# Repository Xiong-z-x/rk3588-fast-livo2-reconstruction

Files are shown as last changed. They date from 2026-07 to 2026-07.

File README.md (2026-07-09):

# RK3588 / ELF2 FAST-LIVO2 Reconstruction

<p align="center">
  <b>LiDAR-Visual-Inertial mapping stack for Livox Mid-360, Hikrobot MVS camera, STM32 hardware synchronization, ROS1 Noetic and WebGL visualization.</b>
</p>

<p align="center">
  
  
  
  
  
</p>

This repository collects the source code, launch scripts, calibration workflow, runtime configuration, mechanical design sources and visualization tools used in an embedded 3D reconstruction system. The project integrates Livox Mid-360 LiDAR, a Hikrobot industrial camera, STM32 hardware triggering and a ROS1 Docker runtime on an RK3588/ELF2-class board.

The repository is organized as a reproducible engineering package rather than a raw experiment dump. It contains the actual project source code, launch scripts, configuration templates, mechanical design sources, public submission materials and selected media assets. Large runtime data products such as rosbag files, PCD files and WebGL caches are intentionally excluded.

## Project Gallery

### Hardware

| Handheld acquisition kit | UAV platform |
| --- | --- |
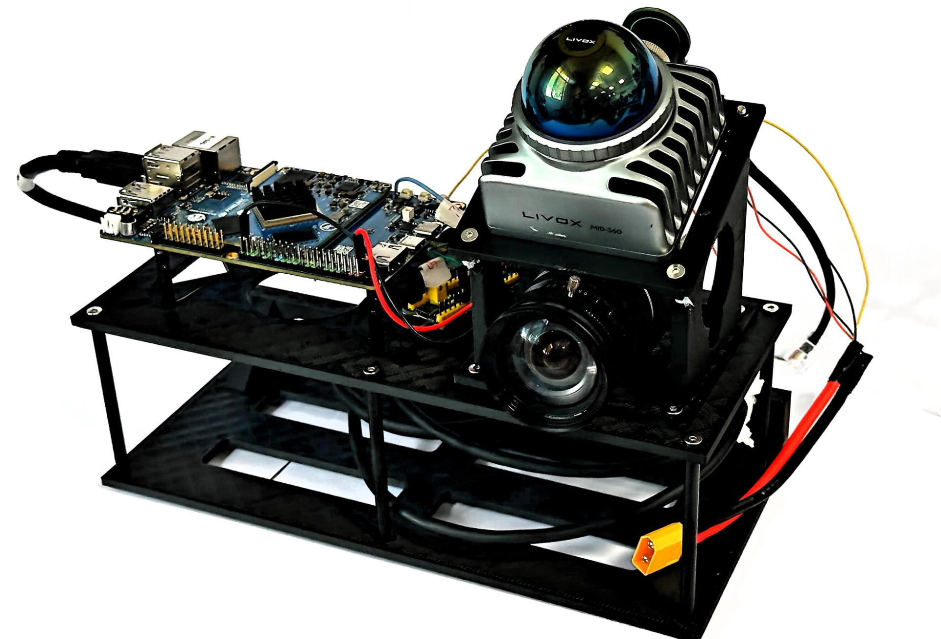
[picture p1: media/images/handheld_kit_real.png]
Handheld LiDAR-camera acquisition kit
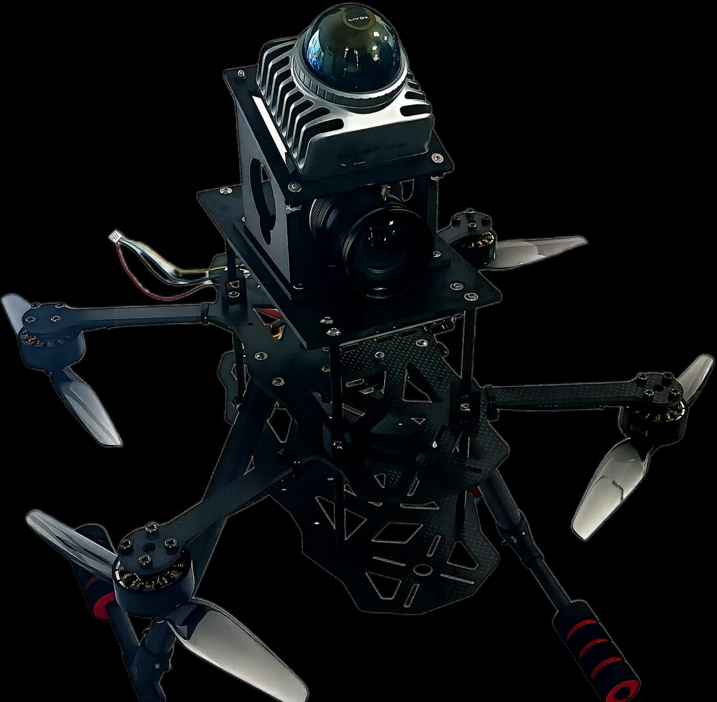
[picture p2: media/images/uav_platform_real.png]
UAV platform with mounted LiDAR-camera module
|  |  |

### Demonstration Videos

| Project demonstration | Progressive reconstruction | Point cloud result viewer |
| --- | --- | --- |
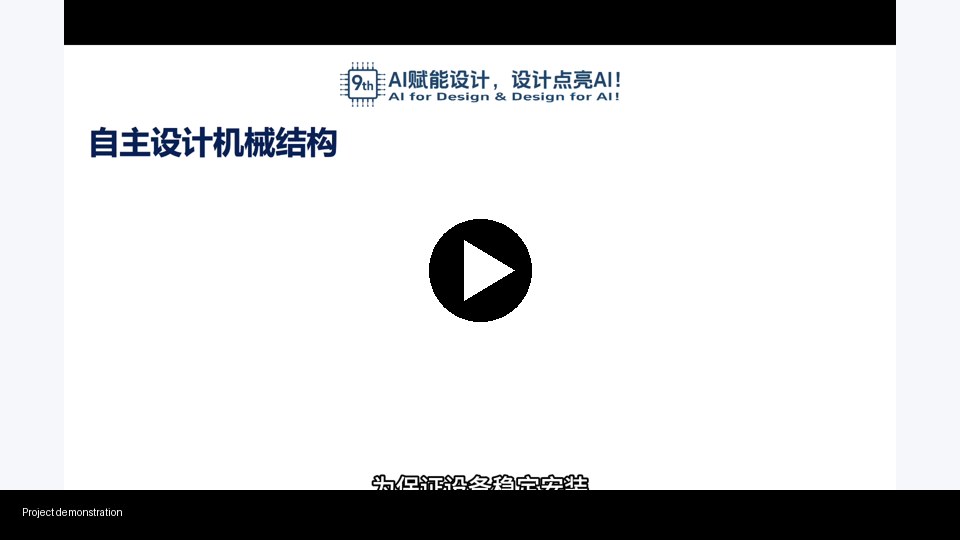
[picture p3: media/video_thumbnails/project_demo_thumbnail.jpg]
Project demonstration video
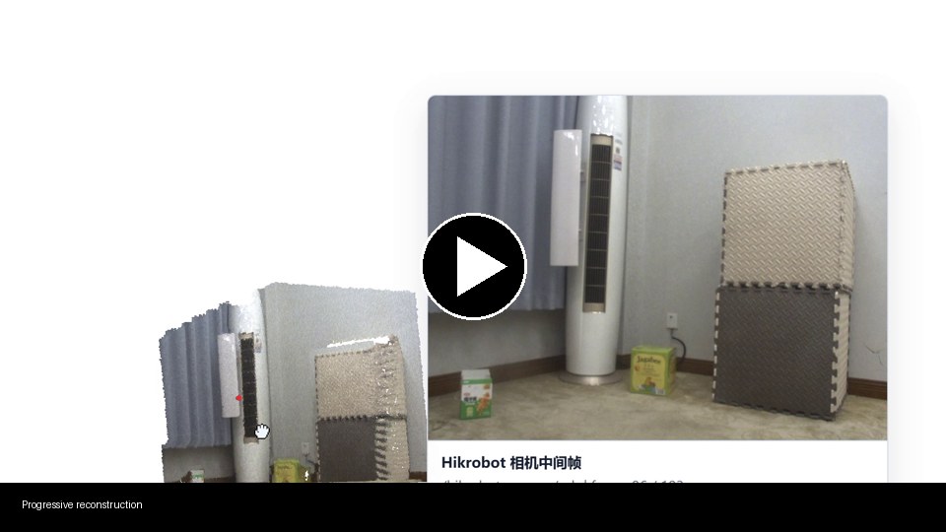
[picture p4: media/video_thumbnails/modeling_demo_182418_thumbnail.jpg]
Progressive reconstruction video
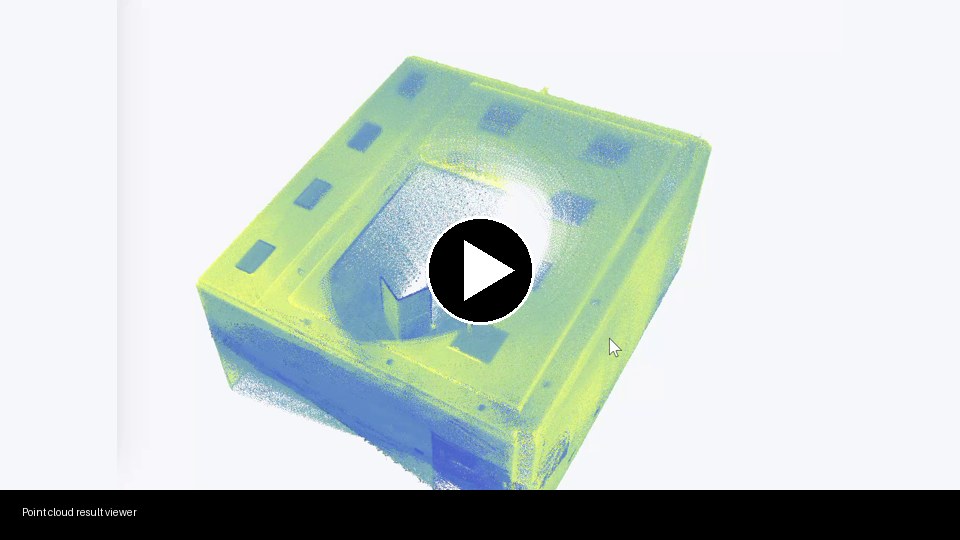
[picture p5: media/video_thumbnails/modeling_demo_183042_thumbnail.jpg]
Point cloud result viewer video
|  |  |  |

Click each thumbnail to open the original MP4 demonstration video.

## Highlights

- FAST-LIVO2-based LiDAR-visual-inertial reconstruction adapted for Mid-360 and Hikrobot image topics.
- LiDAR-only / ONLY_LIO workflow for scenes where the camera or hardware trigger is unavailable.
- Raw ROS bag acquisition scripts for `/livox/lidar`, `/livox/imu`, `/hikrobot_camera/rgb` and `/hikrobot_camera/camera_info`.
- Timestamp inspection utilities for camera duplicate stamps, frame gaps and synchronization diagnosis.
- Targetless visual-LiDAR extrinsic calibration workflow based on `direct_visual_lidar_calibration`.
- Point cloud export tools for colored FAST-LIVO2 output, registered intensity output, raw Livox accumulation and pose-accumulated height coloring.
- WebGL viewers for static multi-layer point clouds and progressive reconstruction playback.
- Read-only runtime dashboard with a real edge-status backend for ROS, Docker, CPU, memory and RKNPU status.

## Verification Status

This repository contains the project source files and engineering assets used in the RK3588/ELF2 reconstruction workflow. The committed source tree has passed the repository verification checks below:

- `python3 06_source_manifests/verify_submission_static.py`
- `git diff --check`
- Git LFS tracking for large MP4 media assets

The verification covers line endings, shell syntax, Python syntax, configuration templates, package layout, FAST-LIVO2/Livox dependency consistency and dashboard backend structure. Board deployment and reproduction steps are documented in [README_REPRODUCE.md](README_REPRODUCE.md).

## System Overview

```mermaid
flowchart LR
  L[Livox Mid-360] -->|/livox/lidar 10 Hz| R[ROS1 Docker]
  I[Mid-360 IMU] -->|/livox/imu 200 Hz| R
  C[Hikrobot camera] -->|/hikrobot_camera/rgb 10 Hz| R
  S[STM32 trigger] -->|hardware pulse| C
  R --> B[raw rosbag]
  B --> F[FAST-LIVO2 offline mapping]
  B --> O[ONLY_LIO mapping]
  F --> P[point cloud processing]
  O --> P
  P --> W[WebGL / RViz visualization]
```

## Repository Layout

```text
00_project_configuration/          Runtime topics, Docker, sensor and calibration templates
01_acquisition_and_recording/      Raw bag and LiDAR-only acquisition scripts
02_reconstruction_and_mapping/     FAST-LIVO2 offline, ONLY_LIO and point cloud processing
03_calibration/                    Camera intrinsics and targetless visual-LiDAR calibration scripts
04_visualization/                  WebGL, progressive reconstruction, RViz and ROS publishers
05_realtime_display/               Board status probe and web dashboard
06_source_manifests/               Source provenance records
07_full_source_code/               ELF2-adapted upstream source trees and project adaptation configs
08_edge_measurement_runtime/        Edge measurement and runtime integration programs
mechanical_design/                 SolidWorks mechanical design sources
media/                             Hardware images and demonstration videos
提交材料/                            Official submission package
submission_materials/              Final report and authorization material
docs/design/                       Architecture, synchronization, calibration and visualization notes
docs/evidence/                     Reproducibility records for build, rosbag, sync, runtime and reconstruction results
```

## Source Trees

The source directories are named with an `elf2` suffix to identify this repository's integration target. Upstream source provenance is preserved in `07_full_source_code/source_provenance/SOURCE_PROVENANCE.yaml`.

| Directory | Purpose |
| --- | --- |
| `07_full_source_code/FAST-LIVO2_elf2_mid360_hik/` | FAST-LIVO2 source tree used as the mapping core |
| `07_full_source_code/FAST-LIVO2_project_adaptation/` | Mid-360, Hikrobot and ONLY_LIO launch/config adaptation |
| `07_full_source_code/livox_ros_driver2_elf2_mid360/` | Livox ROS Driver2 source tree |
| `07_full_source_code/livox_ros_driver2_project_config/` | Mid-360 network config template for the board |
| `07_full_source_code/mvs_ros_driver_elf2_hikrobot/` | Hikrobot MVS ROS driver source tree |
| `07_full_source_code/mvs_ros_driver_project_config/` | Hikrobot trigger and calibration config template |
| `07_full_source_code/direct_visual_lidar_calibration_elf2/` | Targetless visual-LiDAR calibration source tree |

## Mechanical Design

The repository includes the SolidWorks source package imported from `D:\solidworks` under [`mechanical_design/solidworks_sources`](mechanical_design/solidworks_sources). The design files cover the E200 UAV platform, handheld acquisition fixture and embedded mounting structures for the Livox Mid-360, Hikrobot camera and RK3588/ELF2-class board.

The imported mechanical source package contains 697 valid design/reference files after excluding SolidWorks temporary lock files. CAD assets are tracked with Git LFS.

## Media and Submission Materials

- [云顶智量-展示视频](提交材料/云顶智量-展示视频.mp4)
- [云顶智量-报告](提交材料/云顶智量-报告.pdf)
- [云顶智量-代码](提交材料/云顶智量-代码.rar)
- [云顶智量-授权书](提交材料/云顶智量-授权书.pdf)
- [Final project report](submission_materials/yunding_zhiliang_final_report.pdf)
- [Authorization document](submission_materials/authorization.pdf)
- [Project demonstration video](media/videos/yunding_zhiliang_demo.mp4)
- [Reconstruction screen recording 2026-07-07 18:24](media/videos/modeling_reconstruction_demo_20260707_182418.mp4)
- [Reconstruction screen recording 2026-07-07 18:30](media/videos/modeling_reconstruction_demo_20260707_183042.mp4)

Large MP4 assets are tracked with Git LFS to keep the Git history usable while preserving the original submission videos.

## Runtime Environment

- Board class: RK3588 / ELF2
- ROS distribution: ROS1 Noetic
- Container model: Docker with host networking
- Primary LiDAR topic: `/livox/lidar`
- Primary IMU topic: `/livox/imu`
- Primary camera topic: `/hikrobot_camera/rgb`
- Camera info topic: `/hikrobot_camera/camera_info`
- Recommended offline playback rate: `0.5x` for stable reconstruction on limited embedded hardware

Public hardware configuration templates are named `.example.*`. Copy them to local files and fill in the actual serial numbers, MAC addresses and IP addresses before deployment. See [README_REPRODUCE.md](README_REPRODUCE.md) for the exact copy, validation, build and run sequence.

## Quick Start

Assemble the ROS1 workspace from the packaged source trees:

```bash
export RK3588_ROS_CONTAINER=${RK3588_ROS_CONTAINER:-rk3588_dev}
export RK3588_WS=${RK3588_WS:-/root/fast_lio2_ws}

./00_project_configuration/create_catkin_workspace_from_submission.sh \
  --workspace "$RK3588_WS" \
  --copy
```

Use `--with-calibration` only when the review machine also has the dependencies required by `direct_visual_lidar_calibration`.

Build the ROS1 workspace on the target runtime:

```bash
cd "$RK3588_WS"
catkin_make
source devel/setup.bash
```

Record raw LiDAR, IMU and camera topics:

```bash
01_acquisition_and_recording/raw_full_bag_recording/host_start_raw_bag.sh demo_scene
01_acquisition_and_recording/raw_full_bag_recording/host_stop_raw_bag.sh
```

Record LiDAR-only data with automatic stop:

```bash
LIO_BAG_DURATION_SEC=180 \
01_acquisition_and_recording/lidar_only_recording/host_start_lidar_only_bag.sh demo_lio_scene
```

Run FAST-LIVO2 offline reconstruction:

```bash
FAST_LIVO2_PLAY_RATE=0.5 \
FAST_LIVO2_POST_PLAY_WAIT_SEC=60 \
02_reconstruction_and_mapping/fast_livo2_offline/run_fast_livo2_offline_bag.sh \
  /path/to/raw.bag /path/to/run_dir
```

Run ONLY_LIO reconstruction:

```bash
FAST_LIVO2_PLAY_RATE=0.5 \
FAST_LIVO2_POST_PLAY_WAIT_SEC=60 \
02_reconstruction_and_mapping/fast_livo2_only_lio_offline/run_fast_livo2_only_lio_offline_bag.sh \
  /path/to/lidar_only.bag /path/to/run_dir
```

## Visualization

Generate a static multi-layer WebGL viewer:

```bash
python3 04_visualization/webgl_and_progressive_viewers/create_pcd_direct_webgl_viewer.py \
  --result-dir /path/to/result \
  --output-dir /path/to/result/webgl_viewer
```

Generate progressive reconstruction playback from `lidar_poses.txt` and raw bag data:

```bash
python3 04_visualization/webgl_and_progressive_viewers/create_progressive_frame_index_from_bag.py \
  --bag /path/to/raw.bag \
  --poses /path/to/result/lidar_poses.txt \
  --output /path/to/result/progressive_frames

python3 04_visualization/webgl_and_progressive_viewers/create_progressive_reconstruction_viewer.py \
  --frames /path/to/result/progressive_frames \
  --output-dir /path/to/result/progressive_reconstruction_viewer
```

## Runtime Dashboard

Start the read-only edge status backend on the board or inside the ROS host:

```bash
python3 05_realtime_display/tools/rk3588_edge_status_server.py \
  --host 127.0.0.1 \
  --port 8766 \
  --container "${RK3588_ROS_CONTAINER:-rk3588_dev}" \
  --workspace "${RK3588_WS:-/root/fast_lio2_ws}"
```

Run the web dashboard:

```bash
cd 05_realtime_display/web_dashboard
npm ci
npm run dev
```

The dashboard fetches `/api/status` through the Vite proxy. It does not fabricate live metrics: if the backend or ROS master is unavailable, the page shows waiting or error states. This component is an edge status panel for Docker, ROS topics, CPU, memory and RKNPU status; point-cloud browsing is handled by the WebGL viewers under `04_visualization`.

For Foxglove readiness checks, `05_realtime_display/tools/rk3588_display_probe.py` defaults to read-only mode, validates Docker container names, rejects unknown SSH host keys by default and binds bridge startup to `127.0.0.1` unless a different address is explicitly supplied.

Recommended static viewer layers:

- `lidar_pose_mapped_height_full`
- `fast_livo2_registered_intensity_full`
- `trajectory`
- `lidar_pose_mapped_height_stride10`
- `livox_raw_stride10`
- `livox_raw_full`

## Documentation

- [Architecture](docs/design/architecture.md)
- [Hardware synchronization](docs/design/hardware_synchronization.md)
- [Calibration workflow](docs/design/calibration_workflow.md)
- [Reconstruction and visualization](docs/design/reconstruction_visualization.md)
- [Source provenance](07_full_source_code/source_provenance/SOURCE_PROVENANCE.yaml)
- [Reproduction guide](README_REPRODUCE.md)
- [Evidence templates](docs/evidence/)

## Static Checks

Run the submission consistency check before packaging:

```bash
python3 06_source_manifests/verify_submission_static.py
```

The check verifies the FAST-LIVO2/Livox Driver2 dependency, Mid-360 parameter namespace, Hikrobot trigger/CameraInfo integration, dashboard live adapter/backend presence and runtime script safety constraints.

## Data Policy

The repository intentionally excludes:

- raw `.bag` recordings
- generated `.pcd`, `.ply`, `.bin`, `.npy` and `.npz` point cloud artifacts
- WebGL build/cache outputs
- browser caches
- editable report `.docx` drafts
- private SSH keys, tokens, real hardware serial numbers and MAC addresses

Public submission PDFs, selected report images and demonstration videos are intentionally included under `submission_materials/` and `media/`.

## Third-Party Notice

This repository includes selected upstream source trees for reproducibility and competition review. Their original licenses and copyright notices remain with the respective source files. Project-specific scripts, configuration templates and documentation are provided for the ELF2/RK3588 reconstruction integration workflow.

## Acknowledgements

This project builds on the following open-source projects:

- [FAST-LIVO2](https://github.com/hku-mars/FAST-LIVO2)
- [Livox ROS Driver2](https://github.com/Livox-SDK/livox_ros_driver2)
- [mvs_ros_driver](https://github.com/flywave/mvs_ros_driver)
- [direct_visual_lidar_calibration](https://github.com/koide3/direct_visual_lidar_calibration)

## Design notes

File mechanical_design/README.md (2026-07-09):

# Mechanical Design Sources

This directory stores the mechanical design source files used by the project.

## Source Package

`solidworks_sources/` is imported from the local design source directory `D:\solidworks`. It contains the E200 UAV platform, handheld acquisition fixture and embedded mounting structures used around the Livox Mid-360, Hikrobot camera and RK3588/ELF2-class board.

Imported source summary:

| Directory | Content |
| --- | --- |
| `solidworks_sources/E200/` | UAV platform assembly, propulsion/motor models, board mounting parts and imported component models |
| `solidworks_sources/手持件/` | Handheld data-acquisition fixture assembly and part files |
| `solidworks_sources/嵌入式/` | Embedded board, LiDAR-camera mounting and protective-shell design variants |

File summary after excluding SolidWorks temporary lock files:

| Type | Count | Size |
| --- | ---: | ---: |
| SolidWorks assemblies `.SLDASM/.sldasm` | 513 | 135.44 MB |
| SolidWorks parts `.SLDPRT/.sldprt` | 172 | 126.59 MB |
| STEP models `.STEP/.step` | 3 | 52.71 MB |
| STL models `.STL/.stl` | 3 | 1.14 MB |
| 3MF reference models `.3MF/.3mf` | 3 | 0.31 MB |
| PNG reference images `.png` | 3 | 2.67 MB |

CAD files are tracked with Git LFS.

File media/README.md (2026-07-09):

# Media Assets

This directory contains public media assets used by the repository README and submission package.

## Images

The hardware images in `images/` were extracted from the final project report:

| File | Description |
| --- | --- |
| `images/handheld_kit_real.png` | Real handheld acquisition kit with Livox Mid-360, Hikrobot camera and ELF2/RK3588-class board |
| `images/uav_platform_real.png` | Real UAV platform with mounted LiDAR-camera module |

## Videos

The MP4 files in `videos/` are tracked with Git LFS. The thumbnails in `video_thumbnails/` are extracted from the original videos and are used by the repository README.

| File | Description |
| --- | --- |
| `videos/yunding_zhiliang_demo.mp4` | Project demonstration video |
| `videos/modeling_reconstruction_demo_20260707_182418.mp4` | Reconstruction / modeling screen recording |
| `videos/modeling_reconstruction_demo_20260707_183042.mp4` | Reconstruction / modeling screen recording |

| Thumbnail | Linked video |
| --- | --- |
| `video_thumbnails/project_demo_thumbnail.jpg` | `videos/yunding_zhiliang_demo.mp4` |
| `video_thumbnails/modeling_demo_182418_thumbnail.jpg` | `videos/modeling_reconstruction_demo_20260707_182418.mp4` |
| `video_thumbnails/modeling_demo_183042_thumbnail.jpg` | `videos/modeling_reconstruction_demo_20260707_183042.mp4` |

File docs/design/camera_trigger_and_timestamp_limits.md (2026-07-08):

# Camera Trigger and Timestamp Limits

The Hikrobot ROS driver exposes the external trigger settings through ROS parameters:

- `TriggerEnable`
- `TriggerMode`
- `TriggerSource`
- `LineSelector`

At startup, the driver prints the configured values before applying them through the Hikrobot MVS SDK. This is intended to make review and field debugging possible from logs.

For the project hardware, the STM32 trigger line should be verified against the Hikrobot MVS feature tree for the exact camera model. Numeric enum values such as `TriggerSource: 0` and `LineSelector: 0` are SDK/model-specific and must not be treated as universal constants without vendor documentation or MVS runtime inspection.

Current ROS image timestamps are assigned with `ros::Time::now()` when the image is published. This is not a strict hardware exposure timestamp. Therefore the technically correct claim is:

- STM32 external triggering controls camera exposure cadence.
- ROS timestamps support ROS-side approximate alignment and diagnostics.
- Strict synchronization claims require additional evidence, such as camera hardware timestamps, trigger sequence IDs, or measured synchronization error statistics.

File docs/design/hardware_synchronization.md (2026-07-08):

# Hardware Synchronization

## Purpose

Hardware synchronization is used to reduce timestamp drift between the camera stream and the LiDAR/IMU stream. In this project, the camera is configured in trigger mode and driven by an STM32 pulse output.

The code path is explicit:

- `07_full_source_code/mvs_ros_driver_elf2_hikrobot/include/hikrobot_camera.hpp` reads `TriggerEnable`, `TriggerMode`, `TriggerSource` and `LineSelector` from the ROS parameter tree.
- `07_full_source_code/mvs_ros_driver_elf2_hikrobot/config/camera.yaml` and `07_full_source_code/mvs_ros_driver_project_config/config/left_camera_trigger.example.yaml` set `TriggerMode: 1`, `TriggerSource: 0` and `LineSelector: 0` for the project trigger setup.
- The driver prints the configured trigger values at startup. The exact mapping from numeric SDK enum values to a physical line must be verified on the target Hikrobot camera through the MVS feature tree or vendor documentation.
- `07_full_source_code/mvs_ros_driver_elf2_hikrobot/src/hikrobot_camera.cpp` publishes `/hikrobot_camera/rgb` as `RGB8` and fills `/hikrobot_camera/camera_info` from the saved K/D/R/P calibration values.

## Signal Path

```mermaid
flowchart LR
  STM32[STM32 timer output] --> CAM[Hikrobot trigger input]
  CAM --> ROS[ROS image topic]
  LIDAR[Mid-360 LiDAR/IMU] --> ROS
  ROS --> BAG[raw rosbag]
  BAG --> CHECK[timestamp diagnostics]
```

## Diagnostics

The timestamp inspection utilities focus on:

- duplicate `header.stamp` values in image and camera_info messages
- large frame gaps in the camera stream
- topic rate consistency for LiDAR, IMU, image and camera_info topics
- continuity of reconstructed pose for static tests

For static tests, the expected pose trajectory should remain nearly fixed. A visible pose jump is treated as a mapping or synchronization symptom that needs investigation before judging point cloud quality.

## Practical Notes

The project keeps a LiDAR-only fallback path. If the camera trigger chain is unstable or unavailable, ONLY_LIO mode can still produce a pose trajectory and height-colored LiDAR reconstruction from Mid-360 LiDAR + IMU data.

ROS image timestamps are assigned when the image is published. They are suitable for ROS-side approximate alignment diagnostics but should not be described as strict hardware exposure timestamps unless additional hardware timestamp or synchronization-error evidence is supplied.

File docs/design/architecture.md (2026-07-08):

# Architecture

## Goal

The system targets embedded LiDAR-visual-inertial reconstruction on an RK3588/ELF2-class board. The practical design objective is to keep online acquisition simple and reliable, then run deterministic offline reconstruction from recorded ROS bags.

## Hardware Blocks

- Livox Mid-360 provides non-repetitive LiDAR packets and IMU measurements.
- Hikrobot MVS camera provides RGB images under external trigger mode.
- STM32 generates the hardware trigger pulse used by the camera synchronization path.
- RK3588/ELF2 runs ROS1 Noetic inside Docker with host networking.
- A workstation can be used for offline result inspection and WebGL delivery.

## Software Blocks

```mermaid
flowchart TB
  subgraph Board
    D[Docker / ROS1 Noetic]
    L[livox_ros_driver2]
    C[mvs_ros_driver]
    R[bag recording scripts]
  end

  subgraph Offline
    F[FAST-LIVO2]
    O[ONLY_LIO mode]
    P[point cloud processing]
    W[WebGL and RViz viewers]
  end

  L --> D
  C --> D
  D --> R
  R --> F
  R --> O
  F --> P
  O --> P
  P --> W
```

## Design Decision

The acquisition path records raw sensor topics only. FAST-LIVO2 is not run during the critical data collection step. This avoids coupling capture reliability to mapping CPU load and makes each reconstruction run reproducible.

## Key ROS Topics

- `/livox/lidar`: `livox_ros_driver2/CustomMsg`
- `/livox/imu`: `sensor_msgs/Imu`
- `/hikrobot_camera/rgb`: `sensor_msgs/Image`
- `/hikrobot_camera/camera_info`: `sensor_msgs/CameraInfo`

## Runtime Boundaries

The board-side runtime is optimized for acquisition and sensor drivers. Visualization products are generated offline from result directories. WebGL output is treated as a delivery artifact, not as a live dependency of mapping.

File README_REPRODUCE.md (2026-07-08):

# Reproduction Guide

This guide describes how to reproduce the submitted ROS1 acquisition and reconstruction stack from a clean checkout or extracted archive.

The package targets an RK3588 / ELF2-class board running ROS1 Noetic in Docker. It is not a Gazebo, planner, or flight-control repository. Flight-control attitude closure is assumed to be handled by the flight controller; this package provides perception acquisition, FAST-LIVO2 reconstruction, calibration scripts, point-cloud processing, WebGL visualization, and a read-only edge status panel.

## 1. Runtime Variables

Set these variables before running host-side helper scripts:

```bash
export RK3588_ROS_CONTAINER=${RK3588_ROS_CONTAINER:-rk3588_dev}
export RK3588_WS=${RK3588_WS:-/root/fast_lio2_ws}
export RK3588_HOST=<board-ip>
```

The default ROS container is `rk3588_dev`. The default workspace path is `/root/fast_lio2_ws`.

## 2. Prepare Local Hardware Config

Template files are deliberately named `.example.*` and are not directly runnable. Copy them to local config names and fill in real hardware values:

```bash
cp 00_project_configuration/livox_mid360_network.example.yaml 00_project_configuration/livox_mid360_network.local.yaml
cp 00_project_configuration/hikrobot_camera_trigger.example.yaml 00_project_configuration/hikrobot_camera_trigger.local.yaml
cp 07_full_source_code/livox_ros_driver2_project_config/config/MID360_config_rk3588.example.json \
   07_full_source_code/livox_ros_driver2_project_config/config/MID360_config_rk3588.local.json
cp 07_full_source_code/mvs_ros_driver_project_config/config/left_camera_trigger.example.yaml \
   07_full_source_code/mvs_ros_driver_project_config/config/left_camera_trigger.local.yaml
```

Fill in the Mid-360 broadcast code, LiDAR IP, host NIC IP, Hikrobot serial number, and camera trigger settings before launching sensors.

Validate the local files before use:

```bash
python3 00_project_configuration/validate_local_configs.py \
  00_project_configuration/livox_mid360_network.local.yaml \
  00_project_configuration/hikrobot_camera_trigger.local.yaml \
  07_full_source_code/livox_ros_driver2_project_config/config/MID360_config_rk3588.local.json \
  07_full_source_code/mvs_ros_driver_project_config/config/left_camera_trigger.local.yaml
```

## 3. Assemble ROS1 Workspace

From the extracted repository root:

```bash
./00_project_configuration/create_catkin_workspace_from_submission.sh \
  --workspace "$RK3588_WS" \
  --copy
```

Use `--with-calibration` only when the review machine also has the dependencies required by `direct_visual_lidar_calibration`.

Build:

```bash
cd "$RK3588_WS"
catkin_make
source devel/setup.bash
```

Vendor prerequisites still apply: Livox SDK / Livox ROS Driver2 requirements, Hikrobot MVS SDK, ROS1 Noetic, PCL, OpenCV, Eigen and the FAST-LIVO2 dependencies.

## 4. Start Acquisition

Raw LiDAR + IMU + camera bag:

```bash
01_acquisition_and_recording/raw_full_bag_recording/host_start_raw_bag.sh demo_scene
01_acquisition_and_recording/raw_full_bag_recording/host_stop_raw_bag.sh
```

LiDAR-only bag:

```bash
LIO_BAG_DURATION_SEC=180 \
01_acquisition_and_recording/lidar_only_recording/host_start_lidar_only_bag.sh demo_lio_scene
```

## 5. Run Offline Reconstruction

FAST-LIVO2 visual-LiDAR reconstruction:

```bash
FAST_LIVO2_PLAY_RATE=0.5 \
FAST_LIVO2_POST_PLAY_WAIT_SEC=60 \
02_reconstruction_and_mapping/fast_livo2_offline/run_fast_livo2_offline_bag.sh \
  /path/to/raw.bag /path/to/run_dir
```

ONLY_LIO reconstruction:

```bash
FAST_LIVO2_PLAY_RATE=0.5 \
FAST_LIVO2_POST_PLAY_WAIT_SEC=60 \
02_reconstruction_and_mapping/fast_livo2_only_lio_offline/run_fast_livo2_only_lio_offline_bag.sh \
  /path/to/lidar_only.bag /path/to/run_dir
```

Expected outputs include `all_raw_points.pcd`, registered intensity PCD, `lidar_poses.txt`, pose-accumulated height-colored LiDAR point clouds, stride previews, and WebGL viewer files depending on the run mode.

## 6. Hardware Trigger Interpretation

The Hikrobot driver sets:

- `TriggerEnable`
- `TriggerMode`
- `TriggerSource`
- `LineSelector`

The driver prints the effective values at startup. For the competition hardware, verify from the Hikrobot MVS SDK feature tree that the selected numeric enum maps to the physical trigger line used by the STM32. The code package does not claim camera exposure timestamps are embedded in ROS messages: image messages use `ros::Time::now()` when publishing. The intended engineering statement is that STM32 external trigger controls camera exposure cadence, while ROS timestamps are used for ROS-side approximate alignment unless hardware timestamp/error statistics are supplied.

## 7. Runtime Status Panel

Start the read-only backend:

```bash
python3 05_realtime_display/tools/rk3588_edge_status_server.py \
  --host 127.0.0.1 \
  --port 8766 \
  --container "$RK3588_ROS_CONTAINER" \
  --workspace "$RK3588_WS"
```

Start the web app:

```bash
cd 05_realtime_display/web_dashboard
npm ci
npm run dev
```

This panel reports Docker, ROS topics, CPU, memory and RKNPU status. It is an edge status panel, not a full measurement GUI by itself. Full point-cloud viewing is provided by the WebGL viewers under `04_visualization`.

## 8. Verification Commands

Run before packaging:

```bash
python3 06_source_manifests/verify_submission_static.py
PYTHONDONTWRITEBYTECODE=1 python3 -m unittest discover -s 05_realtime_display/tools/tests
npm --prefix 05_realtime_display/web_dashboard run build
```

If unit tests are run without `PYTHONDONTWRITEBYTECODE=1`, remove generated `__pycache__` directories before packaging.

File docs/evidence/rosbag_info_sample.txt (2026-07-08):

This is a sample evidence slot.

Expected command:

  rosbag info /path/to/raw_full_scene.bag

The captured output should show at least:

  /livox/lidar                    livox_ros_driver2/CustomMsg
  /livox/imu                      sensor_msgs/Imu
  /hikrobot_camera/rgb            sensor_msgs/Image
  /hikrobot_camera/camera_info    sensor_msgs/CameraInfo

Record the duration, message counts, compression type and per-topic message counts
from the real bag used for reconstruction.

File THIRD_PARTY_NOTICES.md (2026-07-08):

# Third-Party Notices

This repository includes selected third-party source trees for reproducible review of the reconstruction stack.

The following components retain their original upstream licenses and notices:

- FAST-LIVO2: https://github.com/hku-mars/FAST-LIVO2
- Livox ROS Driver2: https://github.com/Livox-SDK/livox_ros_driver2
- mvs_ros_driver: https://github.com/flywave/mvs_ros_driver
- direct_visual_lidar_calibration: https://github.com/koide3/direct_visual_lidar_calibration
- nlohmann/json: https://github.com/nlohmann/json
- RapidJSON: https://github.com/Tencent/rapidjson

Project-specific integration scripts, configuration templates and documentation in this repository are intended for the RK3588/ELF2 reconstruction workflow. When redistributing or reusing third-party components, check the license files inside each upstream source tree.

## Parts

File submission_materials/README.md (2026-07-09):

# Submission Materials

This directory contains the public competition submission materials associated with the repository.

| File | Description |
| --- | --- |
| `yunding_zhiliang_final_report.pdf` | Final project report, renamed from the submitted report file for stable repository paths |
| `authorization.pdf` | Authorization document |

Large raw experiment data, rosbag files and point-cloud outputs are not stored here. Reproducible source code, configuration templates and verification scripts are stored in the main project directories.

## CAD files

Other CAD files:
mechanical_design/solidworks_sources/E200/DM Orin NX-CB-V2.1/C46.sldasm
mechanical_design/solidworks_sources/嵌入式/111.SLDASM
mechanical_design/solidworks_sources/E200/DM Orin NX-CB-V2.1/D23.sldasm
mechanical_design/solidworks_sources/E200/DM Orin NX-CB-V2.1/C16.sldasm
mechanical_design/solidworks_sources/嵌入式/手持件+雷达+相机.SLDASM
mechanical_design/solidworks_sources/手持件/手持件.SLDASM
mechanical_design/solidworks_sources/E200/DM Orin NX-CB-V2.1/R117.sldasm
mechanical_design/solidworks_sources/嵌入式/手持件+雷达+相机+板子.SLDASM
mechanical_design/solidworks_sources/E200/DM Orin NX-CB-V2.1/R96.sldasm
mechanical_design/solidworks_sources/E200/DM Orin NX-CB-V2.1/R99.sldasm
mechanical_design/solidworks_sources/E200/DM Orin NX-CB-V2.1/C144.sldasm
mechanical_design/solidworks_sources/E200/DM Orin NX-CB-V2.1/C74.sldasm
mechanical_design/solidworks_sources/E200/E200.SLDASM
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

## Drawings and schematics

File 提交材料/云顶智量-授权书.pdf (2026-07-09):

## 参赛作品承诺及使用授权书

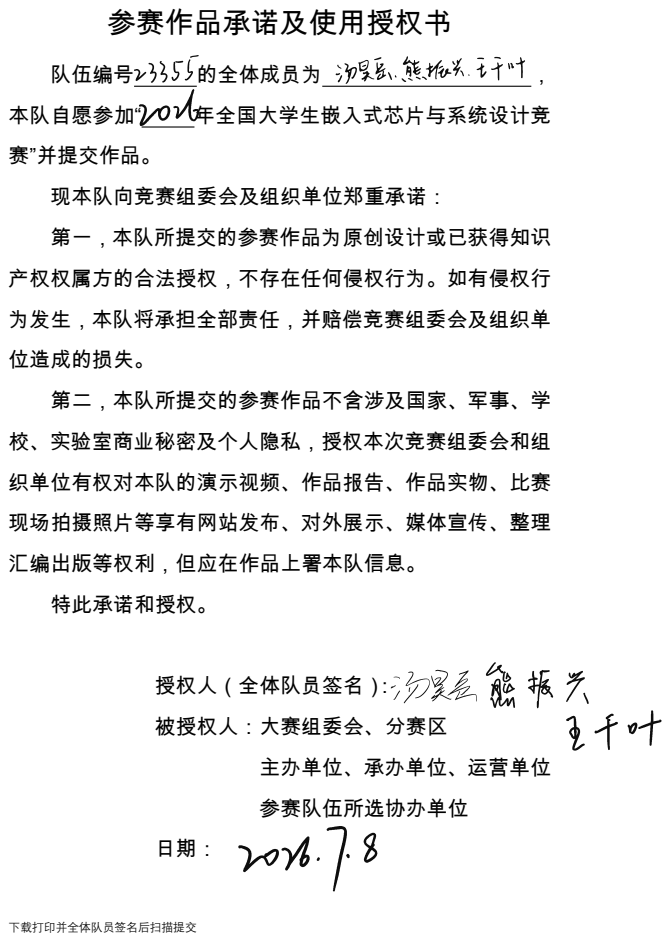
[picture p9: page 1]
下载打印并全体队员签名后扫描提交; 的全体成员为; 年全国大学生嵌入式芯片与系统设计竞; 队伍编号 本队自愿参加“ 赛”并提交作品。

现本队向竞赛组委会及组织单位郑重承诺：
第一，本队所提交的参赛作品为原创设计或已获得知识
产权权属方的合法授权，不存在任何侵权行为。如有侵权行
为发生，本队将承担全部责任，并赔偿竞赛组委会及组织单
位造成的损失
第二，本队所提交的参赛作品不含涉及国家、军事、学
校、实验室商业秘密及个人隐私，授权本次竞赛组委会和组
织单位有权对本队的演示视频、作品报告、作品实物、比赛
现场拍摄照片等享有网站发布、对外展示、媒体宣传、整理
汇编出版等权利，但应在作品上署本队信息。
特此承诺和授权。

授权人（全体队员签名）：
被授权人：大赛组委会、分赛区

主办单位、承办单位、运营单位
参赛队伍所选协办单位

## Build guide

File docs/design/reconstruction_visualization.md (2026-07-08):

# Reconstruction and Visualization

## Reconstruction Modes

### FAST-LIVO2 Mode

FAST-LIVO2 mode consumes LiDAR, IMU and camera image topics. It produces a colored point cloud and a pose trajectory when camera timestamps and extrinsics are valid.

### ONLY_LIO Mode

ONLY_LIO mode disables image input and uses Mid-360 LiDAR + IMU for pose estimation. It is used when camera triggering is unavailable or when a LiDAR-only quality baseline is needed.

## Point Cloud Layers

The visualization pipeline separates layers by meaning:

- colored FAST-LIVO2 map
- registered intensity map
- LiDAR-only pose-accumulated height-colored full map
- stride-10 preview layers
- raw Livox accumulation layers
- pose trajectory

This separation prevents confusing a camera-colored result with a LiDAR-only height-colored result.

## WebGL Viewer Requirements

The static viewer supports:

- unrestricted 360-degree rotation
- mouse wheel zoom
- middle-button pan
- right-button vertical zoom
- `Shift + left button` pan
- reset, top and front views
- hideable side panel
- trajectory rendered as `LINE_STRIP + POINTS`

The trajectory is drawn as an overlay with depth testing disabled so that dense point clouds do not hide the motion path.

## Progressive Reconstruction

The progressive viewer uses `lidar_poses.txt` and raw bag or mapped point data to generate frame-indexed reconstruction playback. This makes the final model appear over time and is useful for demos that need to show the mapping process rather than only the final result.

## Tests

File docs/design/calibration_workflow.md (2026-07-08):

# Calibration Workflow

## Camera Intrinsics

The camera model is pinhole with radial-tangential distortion. The project configuration files store:

- image width and height
- `fx`, `fy`, `cx`, `cy`
- distortion coefficients
- rectified projection matrix when available

Public templates keep the calibrated numeric model but remove device serial numbers.

## Visual-LiDAR Extrinsics

The visual-LiDAR extrinsic workflow uses targetless calibration based on `direct_visual_lidar_calibration`.

General procedure:

1. Record a bag containing LiDAR, IMU and camera topics.
2. Preprocess synchronized visual-LiDAR frames.
3. Provide an initial transform using manual correspondence or a coarse estimate.
4. Run calibration optimization.
5. Export the transform and convert it to the convention expected by FAST-LIVO2.

## Convention Check

One important integration detail is transform direction. Calibration tools and FAST-LIVO2 can expect different forms of camera-to-LiDAR or LiDAR-to-camera transforms. The project keeps `Rcl` and `Pcl` in the FAST-LIVO2 adaptation config and treats transform direction as a first-class validation item.

## Validation

Calibration should be checked using:

- visual overlay quality
- number of colored map points
- whether image content projects to plausible surfaces
- static pose continuity
- point cloud consistency across looped scene motion

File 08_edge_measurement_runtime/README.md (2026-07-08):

# CloudMeasure Edge AI Runtime

This folder contains the production-shaped runtime code for the two AI
extensions added on top of the FAST-LIVO2 point cloud reconstruction package:

1. RK3588 NPU point cloud instance segmentation and VoxelNet-Mini recognition.
2. Neural occupancy field based per-cargo volume estimation.
3. BEV-YOLO candidate detection using a real third-party YOLO checkpoint.

The code is organized as a runtime package. It loads model files from
configured paths, calls RKNN Runtime through
`rknnlite.api.RKNNLite`, parses real `/sys/kernel/debug/rknpu/load` output, and
raises errors when model files or board runtime dependencies are missing.

## Expected model artifacts

Place these files on the ELF2 / RK3588 board or mount them into the runtime
container:

- `models/cargo_instance_seg_int8.rknn`
- `models/voxelnet_mini_cargo_cls_int8.rknn`
- `models/neural_occupancy_field.pt`
- `models/third_party/yolo/yolov8n.pt`

The default paths are defined in `configs/edge_runtime.yaml`.

The YOLO checkpoint is a public Ultralytics YOLOv8n pretrained weight. It is
not a cargo-specific trained model by itself; this package uses it through
`cloudmeasure_edge/bev_yolo_detector.py` as a BEV candidate detector and as a
real initialization checkpoint for later cargo-domain fine-tuning.

Model source, export, conversion, and verification commands are listed in:

- `configs/model_manifest.yaml`

The codebase includes the scripts needed to export ONNX architectures, convert
ONNX to RKNN, train the occupancy field checkpoint, and write a runtime
benchmark JSON file.

## Main entry points

- `cloudmeasure_edge/rknn_runtime.py`
  Loads RKNN models, initializes RK3588 NPU cores, and runs inference. The
  pipeline keeps this runtime initialized across frames.

- `cloudmeasure_edge/pointcloud_segmentation.py`
  Converts FAST-LIVO2 PCD ROI points into BEV/Pillar features, runs the NPU
  segmentation model, and converts model output into object instances. It
  supports both objectness-map output and center-head output
  `heatmap + offset + dimensions + yaw`.

- `cloudmeasure_edge/voxelnet_mini.py`
  Builds a local voxel tensor for each segmented object and runs VoxelNet-Mini
  recognition through RKNN Runtime.

- `cloudmeasure_edge/bev_yolo_detector.py`
  Converts ROI point clouds into a three-channel BEV image
  `density + normalized_z_max + valid_cell`, runs the YOLO checkpoint through
  Ultralytics, and maps detected BEV boxes back to metric point subsets.

- `cloudmeasure_edge/occupancy_field.py`
  Loads a PyTorch neural occupancy field checkpoint and estimates object volume
  by sampling inside each fitted OBB.

- `cloudmeasure_edge/pipeline.py`
  Connects PCD loading, NPU segmentation, VoxelNet recognition, occupancy volume
  estimation, and NPU load monitoring into one result object.

- `cloudmeasure_edge/api.py`
  FastAPI endpoints for integration with the web dashboard.

- `scripts/export_reference_models.py`
  Exports the segmentation and VoxelNet-Mini ONNX model definitions and the
  occupancy field checkpoint structure.

- `scripts/export_occupancy_to_onnx.py`
  Exports a trained occupancy checkpoint to ONNX. The default runtime is
  PyTorch (`occupancy.runtime: torch`), and this script provides the conversion
  path for later RKNN deployment.

- `scripts/run_bev_yolo.py`
  Runs the BEV-YOLO detector against a PCD ROI and prints JSON detections,
  including BEV boxes, mapped metric boxes, point counts, and fitted OBB volume
  where enough points are available.

- `scripts/export_yolo_to_onnx.py`
  Exports the included `yolov8n.pt` checkpoint to ONNX so the BEV-YOLO branch
  can follow the same ONNX to RKNN deployment path as the other models.

- `scripts/convert_onnx_to_rknn.py`
  Converts ONNX models to RKNN with RKNN Toolkit 2.

- `scripts/verify_model_artifacts.py`
  Checks required model files and writes size plus SHA256 metadata.

- `scripts/benchmark_edge_pipeline.py`
  Runs warmup plus repeated inference and writes mean / P95 timing and NPU
  utilization.

- `scripts/build_clean_archive.sh`
  Builds a clean submission zip without macOS metadata, build outputs, caches,
  or dependency folders.

- `training/train_occupancy_field.py`
  Trains the occupancy field from an NPZ dataset containing `query_xyz`,
  `context`, and `occupancy` arrays.

## Example

```bash
python -m cloudmeasure_edge.pipeline \
  --config configs/edge_runtime.yaml \
  --pcd /data/cloudmeasure/pcd/fast_livo2_colored_map.pcd \
  --bbox-min -2 -2 -0.2 \
  --bbox-max 4 3 2.5
```

Run the BEV-YOLO branch:

```bash
python scripts/run_bev_yolo.py \
  --config configs/edge_runtime.yaml \
  --pcd /data/cloudmeasure/pcd/fast_livo2_colored_map.pcd \
  --bbox-min -2 -2 -0.2 \
  --bbox-max 4 3 2.5
```

## API and GUI

Run the API:

```bash
uvicorn cloudmeasure_edge.api:app --host 127.0.0.1 --port 8788
```

The web dashboard client calls:

```text
POST /api/edge-ai/segment-recognize-volume
```

and renders per-cargo label, confidence, occupied volume, total volume, timing,
and NPU load.

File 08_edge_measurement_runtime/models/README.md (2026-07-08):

# Model Directory

Put runtime model artifacts here when running locally, or copy the same files to
the board paths configured in `configs/edge_runtime.yaml`.

Required files:

- `cargo_instance_seg_int8.rknn`
- `voxelnet_mini_cargo_cls_int8.rknn`
- `neural_occupancy_field.pt`
- `third_party/yolo/yolov8n.pt`

The code does not create these files and does not substitute fixed outputs when
they are missing.

`third_party/yolo/yolov8n.pt` is a public Ultralytics YOLOv8n checkpoint used by
the BEV-YOLO adapter as a real pretrained model file. The source URL, checksum,
and intended role are recorded in `../configs/model_manifest.yaml`.

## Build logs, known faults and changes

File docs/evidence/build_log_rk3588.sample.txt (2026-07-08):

This is a sample evidence slot, not a fabricated target build log.

Expected command on the RK3588/ELF2 ROS1 runtime:

  cd /root/fast_lio2_ws
  catkin_make

A real submission build log should include the full stdout/stderr from catkin_make
showing FAST-LIVO2, livox_ros_driver2 and hikrobot_camera compilation results.

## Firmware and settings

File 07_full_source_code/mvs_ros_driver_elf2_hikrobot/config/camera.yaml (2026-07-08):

# Hikrobot USB camera configuration for the ELF2/RK3588 Mid-360 system.
CameraName: hikrobot_camera
SerialNumber: ""
TopicName: /hikrobot_camera/rgb
CameraInfoTopicName: /hikrobot_camera/camera_info
FrameId: hikrobot_camera

width: 1440
height: 1080
Width: 1440
Height: 1080
Offset_x: 0
Offset_y: 0

FrameRateEnable: true
FrameRate: 10
TriggerEnable: 1
TriggerMode: 1
TriggerSource: 0
LineSelector: 0

ExposureTime: 5000
GammaEnable: true
Gamma: 0.7
GainAuto: 2
SaturationEnable: false
Saturation: 128

CameraMatrix: [1363.99324, 0.0, 710.95104, 0.0, 1362.70434, 569.24445, 0.0, 0.0, 1.0]
DistortionCoefficients: [-0.136245, 0.132247, -0.000207, 0.001075, 0.0]
RectificationMatrix: [1.0, 0.0, 0.0, 0.0, 1.0, 0.0, 0.0, 0.0, 1.0]
ProjectionMatrix: [1323.94861, 0.0, 711.47255, 0.0, 0.0, 1335.89893, 569.50401, 0.0, 0.0, 0.0, 1.0, 0.0]

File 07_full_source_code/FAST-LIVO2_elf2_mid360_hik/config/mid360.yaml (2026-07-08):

common:
  img_topic: "/hikrobot_camera/rgb"
  lid_topic: "/livox/lidar"
  imu_topic: "/livox/imu"
  img_en: 1
  lidar_en: 1
  ros_driver_bug_fix: false

extrin_calib:
  extrinsic_T: [0.0, 0.0, 0.0]
  extrinsic_R: [1.0, 0.0, 0.0,
                0.0, 1.0, 0.0,
                0.0, 0.0, 1.0]
  Rcl: [0.001521317694, -0.999976761951, -0.006645385636,
        0.416612140501, 0.00667500765, -0.909059826777,
        0.909083060001, -0.001385579535, 0.416612614055]
  Pcl: [-0.024721033784, -0.205929867793, 0.013730854987]

time_offset:
  imu_time_offset: 0.0
  img_time_offset: 0.0
  lidar_time_offset: 0.0
  exposure_time_init: 0.0

preprocess:
  point_filter_num: 1
  filter_size_surf: 0.10
  lidar_type: 1
  scan_line: 4
  blind: 0.5
  feature_extract_enabled: false

vio:
  max_iterations: 5
  outlier_threshold: 1000
  img_point_cov: 100
  grid_size: 5
  grid_n_height: 17
  patch_size: 8
  patch_pyrimid_level: 3
  normal_en: true
  raycast_en: false
  inverse_composition_en: false
  exposure_estimate_en: true
  inv_expo_cov: 0.2

imu:
  imu_en: true
  imu_int_frame: 30
  acc_cov: 0.5
  gyr_cov: 0.3
  b_acc_cov: 0.0001
  b_gyr_cov: 0.0001
  gravity_est_en: true
  ba_bg_est_en: true

lio:
  max_iterations: 5
  dept_err: 0.02
  beam_err: 0.05
  min_eigen_value: 0.0025
  voxel_size: 0.5
  max_layer: 2
  max_points_num: 50
  layer_init_num: [5, 5, 5, 5, 5]

local_map:
  map_sliding_en: false
  half_map_size: 100
  sliding_thresh: 8

uav:
  imu_rate_odom: false
  gravity_align_en: false

publish:
  dense_map_en: true
  pub_effect_point_en: false
  pub_plane_en: false
  pub_scan_num: 1
  blind_rgb_points: 0.0

evo:
  seq_name: "mid360_hikrobot"
  pose_output_en: false

pcd_save:
  pcd_save_en: true
  type: 0
  colmap_output_en: false
  filter_size_pcd: 0.03
  interval: -1

image_save:
  img_save_en: false
  interval: 1

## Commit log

2026-07-08 Initial ELF2 FAST-LIVO2 reconstruction stack
    [hikrobot_camera_trigger.yaml]
2026-07-08 Fix ELF2 FAST-LIVO2 reproducibility issues
    [LIVMapper.h, camera.yaml, mid360.yaml]
2026-07-08 Harden submission reproducibility and camera topics
2026-07-08 Harden reproducibility checks and runtime docs
    [hikrobot_camera_trigger.example.yaml]
2026-07-09 Add mechanical design and submission media assets
    [底层.SLDPRT, 手持件.SLDASM, 相机底座固定.SLDPRT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]
2026-07-09 Refresh README and add SolidWorks source package
    [0201_C.sldprt, 0201_R.sldprt, 0603_C.sldprt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]
